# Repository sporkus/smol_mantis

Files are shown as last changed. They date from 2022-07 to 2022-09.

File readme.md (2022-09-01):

# Smol Mantis Toolhead

dual 4010 toolhead with Stealthburner style leds for dragon hotend/sherpa mini.

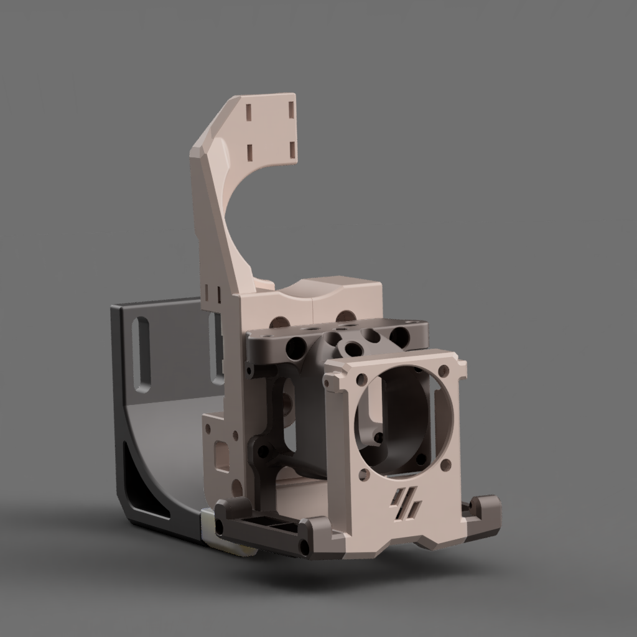
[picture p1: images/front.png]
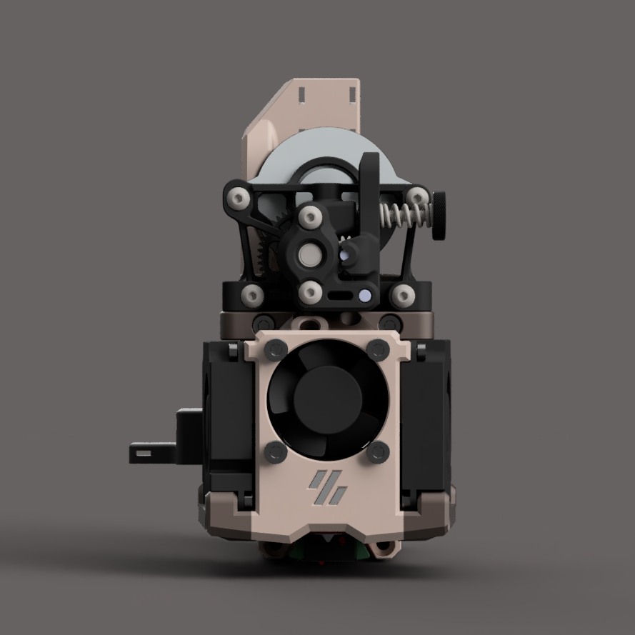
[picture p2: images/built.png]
 

### Features
* Split mgn12 carriage to faciliate belt installation
* mgn12 carriage has integrated umbilical/zipchain anchor
* integrated klickyNG carriage for both mgn9 and mgn12
* SB leds support 
* Removable 4010 fan ducts with large outlets. Should be easy to design and make ducts improvements

### Compatibility
* Toolhead has the same mounting pattern as the stock mantis, and should work with other mantis carriage variants for other probe needs
* KlickyNG is not compatible with original Klicky probes. KlickyNG/unklickyNG probes are much easier to build.
* Dragon SF/HF hotend
* Mosquito hotend (experimental)
* sherpa mini extruder
* folded ascender extruder (experimental)

### BOM
* A bunch of m2x8 and m2x10 self-tapping screws
* Various m3 screws
* heatset m3, 5mm diameter, 4mm tall
* 2x 4010 fans. Delta BFB0412HHA-A or BFB0405HHA-A are recommended
* 1x 3010 fan. Sunon MF30101V1-1000U-A99 
* 2x makerbeam XL m3 nut for MGN9 carriage (printed nuts work but they not last)
* Sherpa mini extruder. [optional front brace](https://github.com/Annex-Engineering/Annex-Engineering_User_Mods/tree/main/Extruders/Sherpa_Mini/Extruder_Mods/Long-housing_front_angled_front_brace)
* Folded ascender extruder
* 3 x 6mmx3mm round magnets
* klickyNG probe

### Credits
* 4010 fan shroud was based on [Minsket's](https://github.com/Minsekt/moronvods/tree/main/Dual_4010_SB_LEDS), but the fan duct has been redesigned for airflow/rigidity/upgradability
* [Long's mantis toolhead](https://github.com/mandryd/VoronUsers/tree/master/printer_mods/Long/Mantis_Dual_5015)
* [Annex Engineering Sherpa Mini extruder](https://github.com/Annex-Engineering/Sherpa_Mini-Extruder)
* [Annex Engineering Folded Ascender extruder](https://github.com/Annex-Engineering/Folded_Ascender-Extruder)
* [KlickyProbe](https://github.com/jlas1/Klicky-Probe)

### Similar designs

* [Mantis Xol](https://github.com/CorvidBuilds/Mantis-Xol): Double folded ascender/dual 4010/rapido
* [DirtyBird toolhead](https://github.com/makerbogans/dirtybird) LGX mini/sherpa/dual 4512/Dragon/NF crazy/Rapido

### Potential issue
* The common 3mm magnets might actually be 2.7mm thick. If they fit too loose in the carriage, please let me know as I only have magnets that are 3mm thick.

### Contact

* Discord: foonietunes #4637

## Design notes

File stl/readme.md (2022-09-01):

## What to print

#### Ducts

    1 each: duct LHS + RHS

#### Front cover

    1: front_cover

#### Toolhead/hotend mount 

    1: toolhead_dragon

#### Carriage 
    1: carriage_mgn9

OR

    1: carriage_mgn12_rhs
    PLUS
    1 of carriage mgn12_lhs variants
    
PLUS

    1: klickyNG_cap

#### KlickyNG dock/gantry mount
    
    1: klickyNG_gantry_mount

#### Optional umbilical/y-endstop pod

     1: umbilical_anchor_body
     1: umbilical_anchor_cap

#### Experimental

    * toolhead for mosquito
    * Ascender base/ mgn12 carriage/ brace

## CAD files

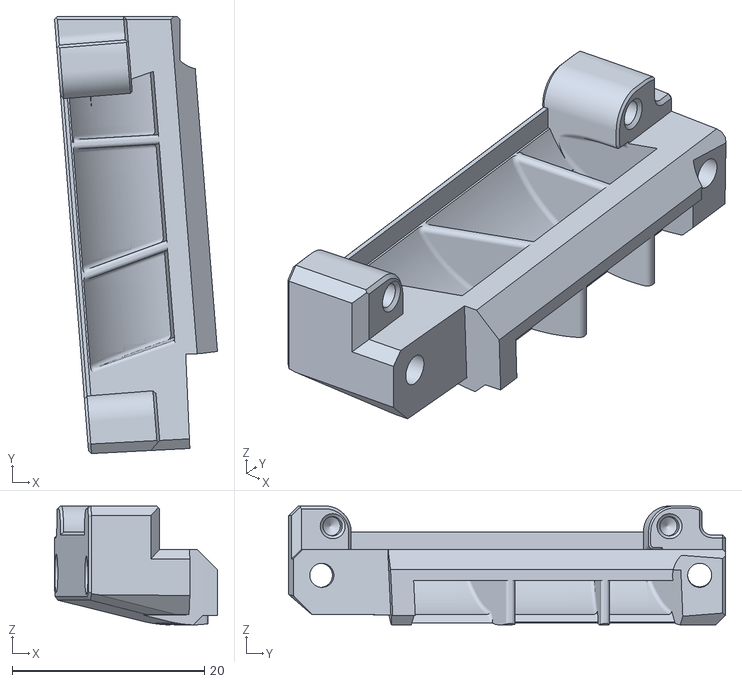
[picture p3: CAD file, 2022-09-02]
stl/experimental/duct test.stl
16.9 x 45.4 x 12.4

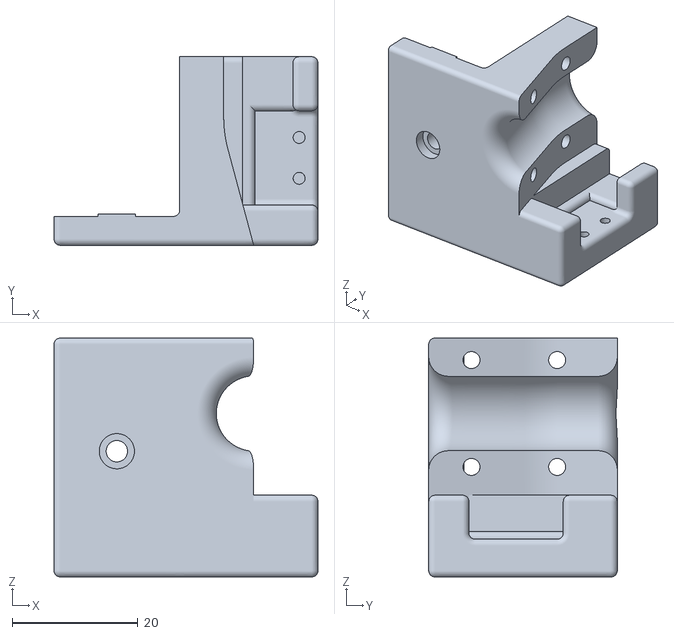
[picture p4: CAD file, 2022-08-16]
stl/optional/umbilical_anchor_body.stl
42.0 x 30.0 x 38.0

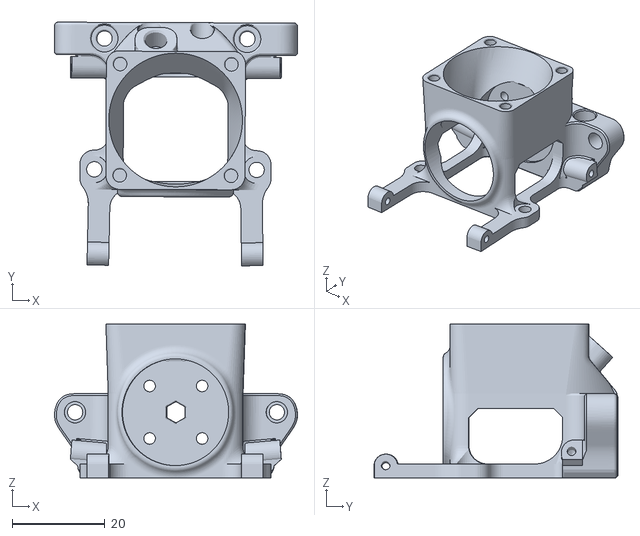
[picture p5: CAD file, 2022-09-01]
stl/toolhead_dragon.stl
52.4 x 52.5 x 33.2

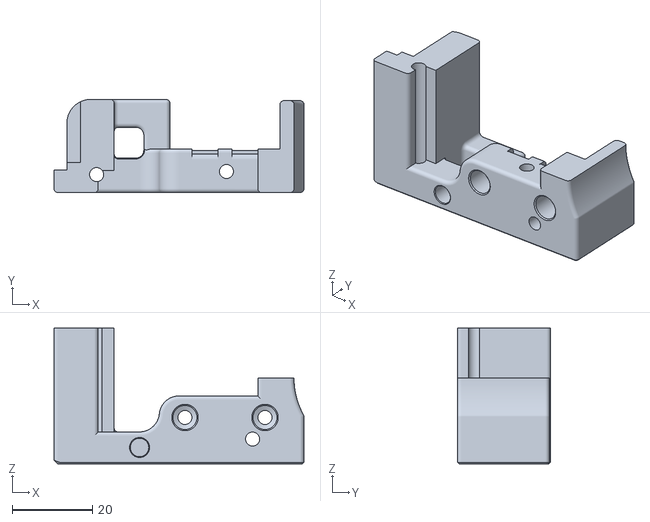
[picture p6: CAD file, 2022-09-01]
stl/carriage_mgn12_rhs.stl
62.5 x 23.3 x 33.9

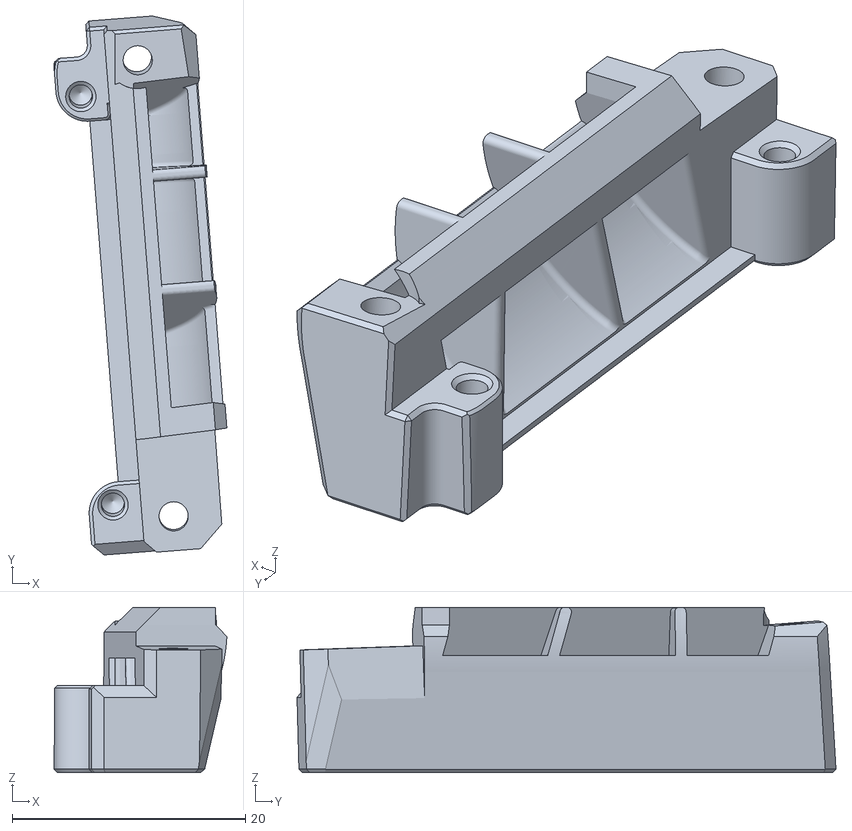
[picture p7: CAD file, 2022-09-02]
stl/experimental/duct_experimental.stl
14.8 x 46.2 x 14.2

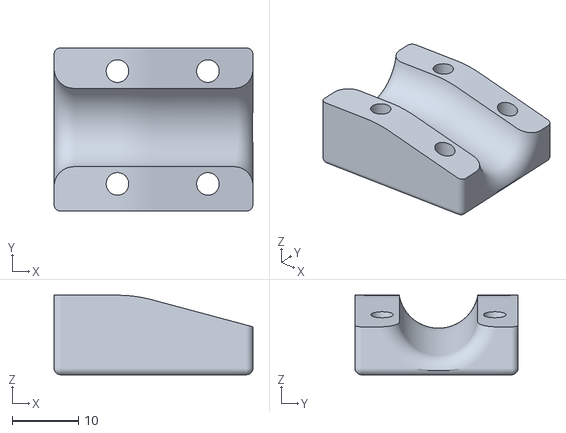
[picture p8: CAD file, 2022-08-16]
stl/optional/umbilical_anchor_cap.stl
30.0 x 24.6 x 12.0

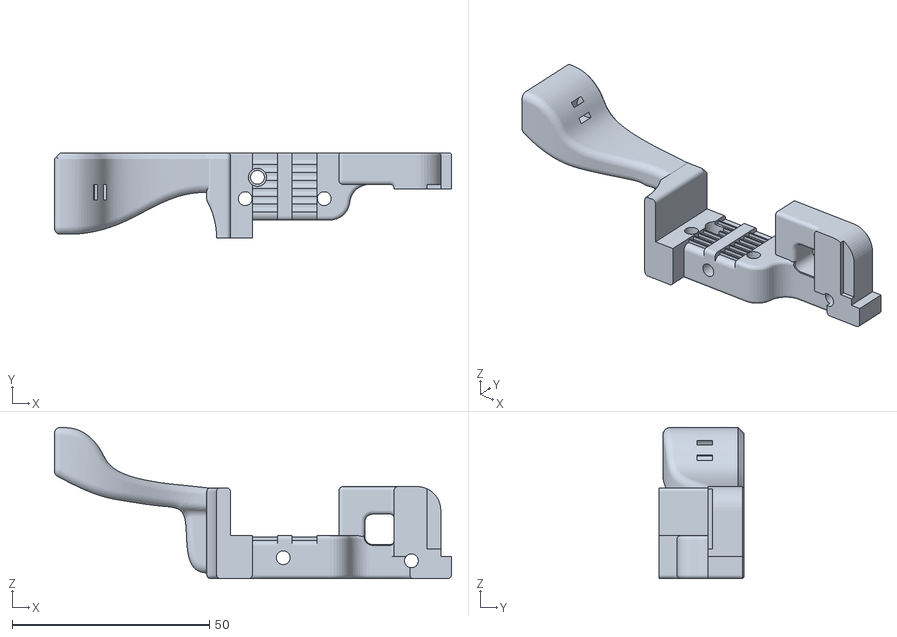
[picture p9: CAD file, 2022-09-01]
stl/carriage_mgn12_lhs_chain.stl
100.5 x 21.6 x 38.3

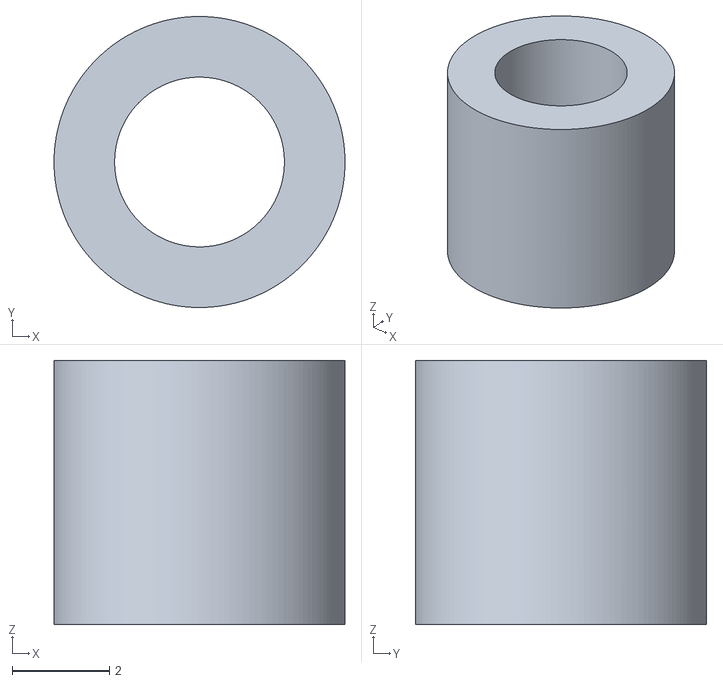
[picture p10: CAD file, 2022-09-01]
stl/experimental/brace_dfa_spacer.stl
6.00 x 6.00 x 5.45

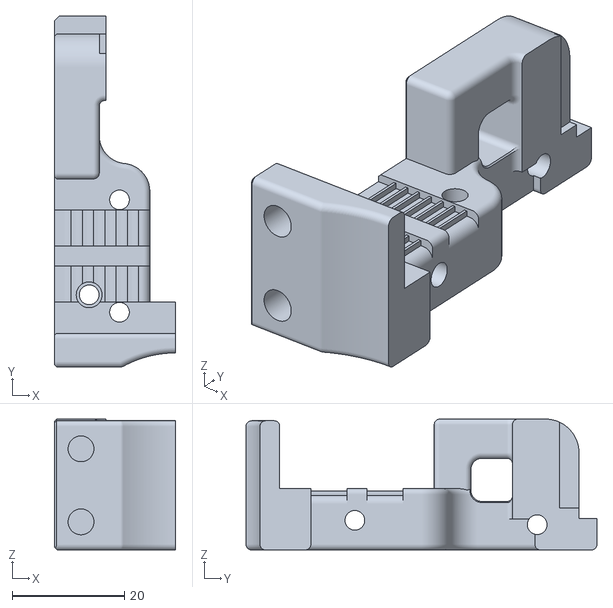
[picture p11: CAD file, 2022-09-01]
stl/carriage_mgn12_lhs.stl
21.6 x 62.5 x 23.3

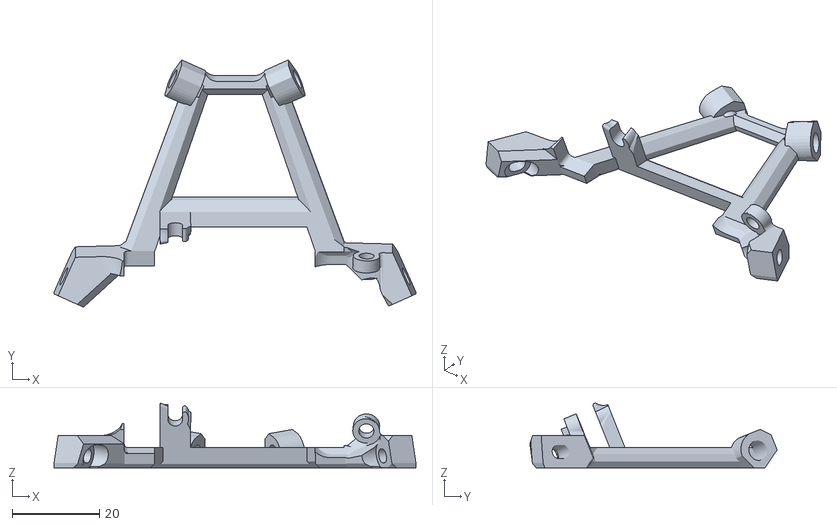
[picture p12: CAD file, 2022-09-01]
stl/experimental/brace_dfa.stl
83.2 x 56.8 x 14.9

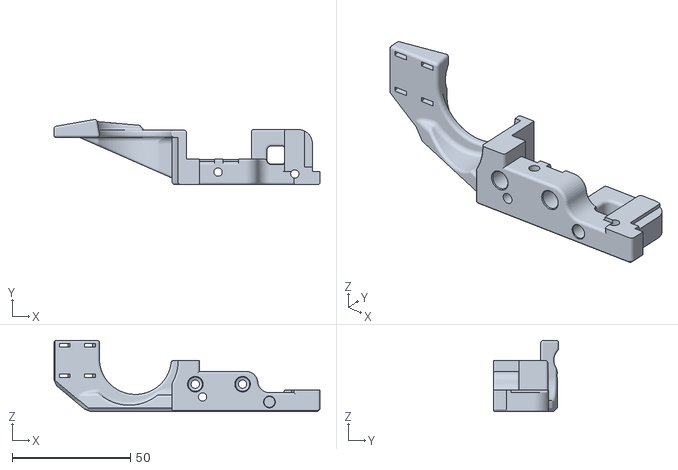
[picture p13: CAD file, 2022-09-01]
stl/carriage_mgn12_lhs_umbilical.stl
112.5 x 27.6 x 30.1

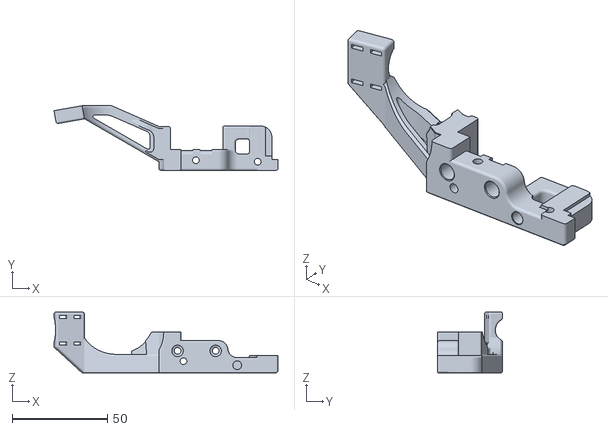
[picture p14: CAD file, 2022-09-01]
stl/experimental/carriage_mgn12_lhs_umbilical_dfa.stl
117.6 x 33.9 x 32.0

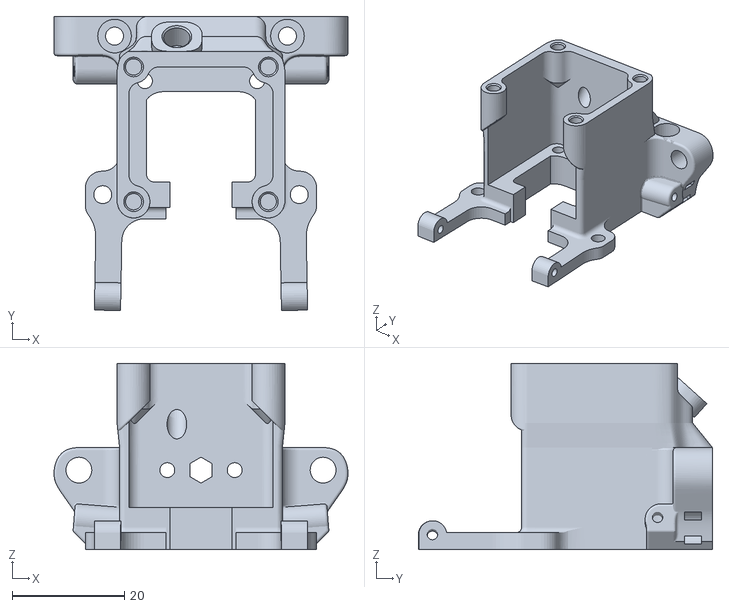
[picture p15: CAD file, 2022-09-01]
stl/experimental/toolhead_mosquito.stl
52.4 x 52.4 x 33.2

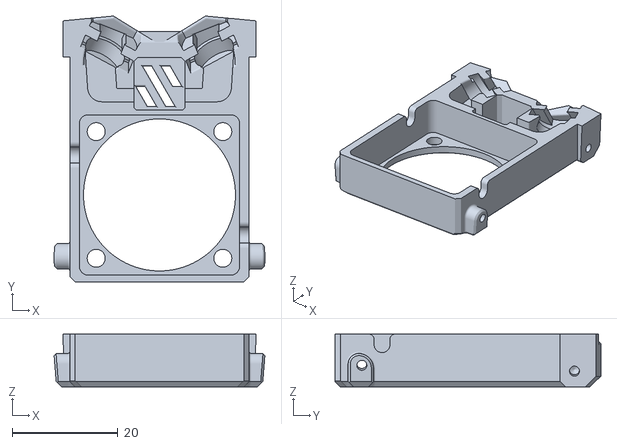
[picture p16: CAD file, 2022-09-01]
stl/front_cover.stl
40.0 x 50.4 x 10.0

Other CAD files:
stl/carriage_mgn9.stl
stl/4010_duct_rhs.stl
stl/4010_duct_lhs.stl
stl/klickyNG_cap.stl
stl/klickyNG_gantry_mount.stl

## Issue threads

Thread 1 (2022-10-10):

euclid compatibility?

Teuflor, 2022-10-10:
Hey,

Minsekt has used his toolhead with nativ euclid probe support. is it possible to adapt this too?

thanks!

Teuflor, 2022-10-10:
dont read the first compatibility point.. sorry

sporkus, 2022-10-13:
> dont read the first compatibility point.. sorry

You should be able to use his carriage. If not, I can look into it.

Closed 2022-10-10.

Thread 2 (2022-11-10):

Not a complaint but a request

kaisarantonn, 2022-11-10:
Not a complaint but a request,
my apologize i dont have expert skills on 3D modelling
but from what i see LDO Orbiter v2 is more famous and the user also a lot.

can you build for orbiter v2 please?

Thank you in advance

HodenKlaus, 2023-01-19:
do u still need this ? i can do this for u.

kaisarantonn, 2023-01-19:
> do u still need this ? i can do this for u.

Yes, that would be awesome
And for the left & right fans is it impossible to make using heatset insert and m3 screw?

I feel using m2 self tap screws and held by screw frictions will make it loose at some points especially when we regularly maintenance the toolhead

sporkus, 2023-01-19:
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

the 4010 holes are too small for m3. Dirty bird uses 4512 with m3

kaisarantonn, 2023-01-19:
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

Oh i see, then maybe for V2 orbiter version can you help me?

sporkus, 2023-01-25:
I'm not gonna do this, but if anyone wants to do a PR i'd be happy to accept.

Closed 2023-01-25.

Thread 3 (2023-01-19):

Fan isnt working

HodenKlaus, 2023-01-19:
It seems like the right fan is getting to hot and don't work.
Seems like a know issue for v0.
Can someone proof or denie this ?
I have this problem on two printers with gdstime Fans.

sporkus, 2023-01-19:
I personally don't have this issue, but I'm using a delta and don't have a v0.

HodenKlaus, 2023-01-21:
i myself dont have a v0. but they also use 40mm fans.
Can u may link the deltas ? They are 5V right ?

sporkus, 2023-01-21:
> i myself dont have a v0. but they also use 40mm fans. Can u may link the deltas ? They are 5V right ?

https://github.com/sporkus/smol_mantis#bom

Closed 2023-01-25.

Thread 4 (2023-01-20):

Longer hotends fan duct feature request

FedorZa, 2023-01-20:
Hello!
Really neat design! but here are definitely lack of longer ducts for longer "volcano-size" hotends (like crazy volcano/rapido)
Basically it's require ducts to be 8mm longer.

Teuflor, 2023-01-20:
would also be interested in! also need for longer hotends an new carriage mount include euclid probe...
i would be switch instantly if this will happen

kostake2011, 2023-01-20:
It would be great. If I could put a chc pro in that toolhead

Solders2004, 2023-01-20:
This is a very comfortable head, but I can't use it with CHC Pro or Volcano and it makes me very sad. the creator will hear our requests and do something about this problem. thanks

Sasha1255, 2023-01-20:
It would be wonderful if the author made long blowing nozzles under chc pro, I would immediately start printing and putting this head on.

sporkus, 2023-01-26:
For Rapido, check out [mantis-Xol](https://github.com/Armchair-Engineering/Mantis-Xol/tree/main/STL).

There's no way to do CHC because that requires a v6 style body.

Either way, you'll likely be cooling limited with the dual 4010.

FedorZa, 2023-01-26:
There are lot of options to mount CHC pro on dragon-style heatsinks.
XOL is over-complicated if you'll ask me :)

Thanks anyway :)

Closed 2023-01-26.

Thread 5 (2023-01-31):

X endstop mount

flow23, 2023-01-31:
Hi,

is there a chance to have an x endstop mount on the toolhead?

sporkus, 2023-01-31:
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
It's there by default (the two m2 holes on the bottom right of the RHS carriage)

Closed 2023-01-31.

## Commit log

2022-07-28 cad init
2022-08-08 improved fan ducts
    [duct L.stl, duct R.stl]
2022-08-08 fix print orientation
    [4010_duct_lhs.stl, 4010_duct_rhs.stl, duct L.stl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]
2022-08-08 really fix print orientation
    [4010_duct_lhs.stl, 4010_duct_rhs.stl]
2022-08-16 added extra clearance for xy joint
    [4010_duct_lhs.stl, 4010_duct_rhs.stl]
2022-08-16 added zip tie holes on the left
    [carriage_mgn12_lhs.stl, carriage_mgn12_lhs_chain.stl, carriage_mgn12_lhs_umbilical.stl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]
2022-08-16 recommend nozzle adxl mount instead
    [adxl_mount.stl]
2022-08-16 added umbilical anchor
    [cable anchor endstop.stl]
2022-08-16 stl doc
2022-08-16 plated umbilical pod
    [cable anchor endstop.stl, umbilical_anchor_body.stl, umbilical_anchor_cap.stl]
2022-08-16 printability fix
    [carriage_mgn9.stl]
2022-08-30 improved wire retention
    [carriage_mgn12_rhs.stl]
2022-09-01 added 3010 fan wiring cutouts
    [front_cover.stl]
2022-09-01 wiring improvements
    [carriage_mgn12_lhs.stl, carriage_mgn12_lhs_chain.stl, carriage_mgn12_lhs_umbilical.stl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]
2022-09-01 mosquito toolhead
    [toolhead_mosquito.stl]
2022-09-01 experimental support for ascender
    [brace_dfa.stl, brace_dfa_spacer.stl, carriage_mgn12_lhs_umbilical_dfa.stl]
2022-09-01 added extra mount hole for dfa
    [toolhead_dragon.stl]
2022-09-02 nozzle test
    [duct test.stl, duct_experimental.stl]
